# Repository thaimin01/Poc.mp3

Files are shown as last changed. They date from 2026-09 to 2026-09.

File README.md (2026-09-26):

# Poc.mp3
A mp3 player that fit into your pocket. With expandable micro sd storage, cool analog and digital VU meter. An AUX output so everyone is happy. All on the esp32

Schematic

finishedschematic

PCB

raytracedpcb

raytracedpcbback

genuineslop

This has 8 buttons, including:

-5 buttons for navigation: Up, Down, Left, Right, Select

-2 buttons for volume changing: Volume up/down

-1 buttons for locking/unlocking

-Features and ESP32-S3 with 8MB of PSRAM and 16MB of flash (N16R8)

-Analog VU meter and two version of digital VU meter (NCS circle and Flat)

-Able to play pretty much most popular audio file with the ability to load the MP3 embeded images

-With SDMMC 1 bit can loads image and music up to 2MB/s (under ideal conditions)

-A 3.5mm jack output with full on Stereo

-Finally a full on UI with home screen and more !

Bill Of Materials

| Reference | Qty | Value | DNP | Exclude from BOM | Exclude from Board | Exclude from Simulation | Exclude from Position Files | Footprint | Datasheet | Cost (USD) | Note |
|---|-----|---|-----|---|---|---|---|---|---|---|---|
| BT1 | 1 | 3.7V | | | | | ${EXCLUDE_FROM_POS_FILES} | Connector_Wire:SolderWire-0.25sqmm_1x02_P4.2mm_D0.65mm_OD1.7mm | | $2 | single |
| C1,C16,C18,C20,C24,C28 | 6 | 0.1uF | | | | | ${EXCLUDE_FROM_POS_FILES} | Capacitor_SMD:C_0603_1608Metric_Pad1.08x0.95mm_HandSolder | | $0.38 | (10pcs per strip) |
| C2,C3,C4,C15,C17,C19,C23,C29 | 8 | 10uF | | | | | ${EXCLUDE_FROM_POS_FILES} | Capacitor_SMD:C_0805_2012Metric_Pad1.18x1.45mm_HandSolder | | $0.50 | (10pcs per strip) |
| C5,C11 | 2 | 22pF | | | | | ${EXCLUDE_FROM_POS_FILES} | Capacitor_SMD:C_0603_1608Metric_Pad1.08x0.95mm_HandSolder | | $0.38 | (10pcs per strip) |
| C6,C7,C8,C9,C10,C12 | 6 | 22uF | | | | | ${EXCLUDE_FROM_POS_FILES} | Capacitor_SMD:C_0805_2012Metric_Pad1.18x1.45mm_HandSolder | | $1.25 | (50pcs per strip) |
| C13,C14,C30 | 3 | 1uF | | | | | ${EXCLUDE_FROM_POS_FILES} | Capacitor_SMD:C_0603_1608Metric_Pad1.08x0.95mm_HandSolder | | $0.38 | (10pcs per strip) |
| C21,C22 | 2 | 2.2uF | | | | | ${EXCLUDE_FROM_POS_FILES} | Capacitor_SMD:C_0603_1608Metric_Pad1.08x0.95mm_HandSolder | | $0.60 | (10pcs per strip) |
| C25,C26 | 2 | 2.2nF | | | | | ${EXCLUDE_FROM_POS_FILES} | Capacitor_SMD:C_0603_1608Metric_Pad1.08x0.95mm_HandSolder | | $0.50 | (10pcs per strip) |
| C27 | 1 | 0.39uF | | | | | ${EXCLUDE_FROM_POS_FILES} | Capacitor_SMD:C_0603_1608Metric_Pad1.08x0.95mm_HandSolder | | $0.38 | (10pcs per strip) |
| C31,C32 | 2 | 100nF | | | | | ${EXCLUDE_FROM_POS_FILES} | Capacitor_SMD:C_0603_1608Metric_Pad1.08x0.95mm_HandSolder | | $0.38 | (10pcs per strip) |
| D1,D2 | 2 | 1N4148W | | | | | ${EXCLUDE_FROM_POS_FILES} | Diode_SMD:D_SOD-123 | https://www.vishay.com/docs/85748/1n4148w.pdf | $1.35 | (200pcs per strip) |
| D3 | 1 | SS34 | | | | | ${EXCLUDE_FROM_POS_FILES} | Diode_SMD:D_SMA | https://www.vishay.com/docs/88751/ss32.pdf | $0.80 | (10pcs per strip) |
| J1 | 1 | USB_C_Receptacle_USB2.0_16P | | | | | ${EXCLUDE_FROM_POS_FILES} | Connector_USB:USB_C_Receptacle_HRO_TYPE-C-31-M-12 | https://www.usb.org/sites/default/files/documents/usb_type-c.zip | $0.60 | single |
| J2 | 1 | 1.8 in TFT screen ST7735 | | | | | ${EXCLUDE_FROM_POS_FILES} | Connector_PinSocket_2.54mm:PinSocket_1x08_P2.54mm_Vertical | | $2.70 | single |
| J4 | 1 | AudioJack3_SwitchTR | | | | | ${EXCLUDE_FROM_POS_FILES} | Connector_Audio:Jack_3.5mm_CUI_SJ2-3593D-SMT_Horizontal | | $1.50 | single |
| J5 | 1 | Micro_SD_Card_Det_Hirose_DM3AT | | | | | ${EXCLUDE_FROM_POS_FILES} | Connector_Card:microSD_HC_Hirose_DM3AT-SF-PEJM5 | https://www.hirose.com/product/en/download_file/key_name/DM3/category/Catalog/doc_file_id/49662/?item_id=195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 | $4 | single |
| L1 | 1 | 4.7 uH | | | | | ${EXCLUDE_FROM_POS_FILES} | Inductor_SMD:L_Taiyo-Yuden_NR-40xx_HandSoldering | | $2 | (5pcs per strip) |
| L2 | 1 | 2.2 uH | | | | | ${EXCLUDE_FROM_POS_FILES} | Inductor_SMD:L_Taiyo-Yuden_NR-40xx_HandSoldering | | $2 | (5pcs per strip) |
| L3 | 1 | 3.3uH | | | | | ${EXCLUDE_FROM_POS_FILES} | Inductor_SMD:L_Taiyo-Yuden_NR-40xx_HandSoldering | | $2 | (5pcs per strip) |
| LS1 | 1 | Speaker | | | | | ${EXCLUDE_FROM_POS_FILES} | Connector_Wire:SolderWire-0.25sqmm_1x02_P4.2mm_D0.65mm_OD1.7mm | | $1 | single |
| Q1 | 1 | 2N7002 | | | | | ${EXCLUDE_FROM_POS_FILES} | Package_TO_SOT_SMD:SOT-23 | https://www.onsemi.com/pub/Collateral/NDS7002A-D.PDF | $1 | 1 $ (50pcs per strip) |
| R1 | 1 | 1K | | | | | ${EXCLUDE_FROM_POS_FILES} | Resistor_SMD:R_0603_1608Metric_Pad0.98x0.95mm_HandSolder | | $1 | (100pcs per strip) |
| R2 | 1 | 0.05 | | | | | ${EXCLUDE_FROM_POS_FILES} | Resistor_SMD:R_0603_1608Metric_Pad0.98x0.95mm_HandSolder | | $1 | (100pcs per strip) |
| R3 | 1 | 453K | | | | | ${EXCLUDE_FROM_POS_FILES} | Resistor_SMD:R_0603_1608Metric_Pad0.98x0.95mm_HandSolder | | $1 | (100pcs per strip) |
| R4 | 1 | 100K | | | | | ${EXCLUDE_FROM_POS_FILES} | Resistor_SMD:R_0603_1608Metric_Pad0.98x0.95mm_HandSolder | | $1 | (100pcs per strip) |
| R5 | 1 | 43K | | | | | ${EXCLUDE_FROM_POS_FILES} | Resistor_SMD:R_0603_1608Metric_Pad0.98x0.95mm_HandSolder | | $1 | (100pcs per strip) |
| R6 | 1 | 440K | | | | | ${EXCLUDE_FROM_POS_FILES} | Resistor_SMD:R_0603_1608Metric_Pad0.98x0.95mm_HandSolder | | $1 | (100pcs per strip) |
| R7 | 1 | 60K | | | | | ${EXCLUDE_FROM_POS_FILES} | Resistor_SMD:R_0603_1608Metric_Pad0.98x0.95mm_HandSolder | | $1 | (100pcs per strip) |
| R8,R9 | 2 | 470 | | | | | ${EXCLUDE_FROM_POS_FILES} | Resistor_SMD:R_0603_1608Metric_Pad0.98x0.95mm_HandSolder | | $1 | (100pcs per strip) |
| R10 | 1 | 20k | | | | | ${EXCLUDE_FROM_POS_FILES} | Resistor_SMD:R_0603_1608Metric_Pad0.98x0.95mm_HandSolder | | $1 | (100pcs per strip) |
| R11,R12 | 2 | 1k | | | | | ${EXCLUDE_FROM_POS_FILES} | Resistor_SMD:R_0603_1608Metric_Pad0.98x0.95mm_HandSolder | | $1 | (100pcs per strip) |
| R13,R15,R16,R23,R24,R25,R26,R29 | 8 | 10k | | | | | ${EXCLUDE_FROM_POS_FILES} | Resistor_SMD:R_0603_1608Metric_Pad0.98x0.95mm_HandSolder | | $1 | (100pcs per strip) |
| R14,R17,R18,R27,R28,R30 | 6 | 100k | | | | | ${EXCLUDE_FROM_POS_FILES} | Resistor_SMD:R_0603_1608Metric_Pad0.98x0.95mm_HandSolder | | $1 | (100pcs per strip) |
| R19,R20 | 2 | 5.1k | | | | | ${EXCLUDE_FROM_POS_FILES} | Resistor_SMD:R_0603_1608Metric_Pad0.98x0.95mm_HandSolder | | $1 | (100pcs per strip) |
| R31 | 1 | 33 | | | | | ${EXCLUDE_FROM_POS_FILES} | Resistor_SMD:R_0603_1608Metric_Pad0.98x0.95mm_HandSolder | | $1 | (100pcs per strip) |
| SW1 | 1 | Up | | | | | ${EXCLUDE_FROM_POS_FILES} | Button_Switch_SMD:SW_SPST_PTS645Sx43SMTR92 | | | |
| SW2 | 1 | Down | | | | | ${EXCLUDE_FROM_POS_FILES} | Button_Switch_SMD:SW_SPST_PTS645Sx43SMTR92 | | | |
| SW3 | 1 | Left | | | | | ${EXCLUDE_FROM_POS_FILES} | Button_Switch_SMD:SW_SPST_PTS645Sx43SMTR92 | | | |
| SW4 | 1 | Right | | | | | ${EXCLUDE_FROM_POS_FILES} | Button_Switch_SMD:SW_SPST_PTS645Sx43SMTR92 | | | |
| SW5 | 1 | Select | | | | | ${EXCLUDE_FROM_POS_FILES} | Button_Switch_SMD:SW_SPST_PTS645Sx43SMTR92 | | $0.60 | (20pcs per package) |
| SW6 | 1 | Volume + | | | | | ${EXCLUDE_FROM_POS_FILES} | Button_Switch_SMD:SW_SPST_PTS645Sx43SMTR92 | | | |
| SW7 | 1 | Volume - | | | | | ${EXCLUDE_FROM_POS_FILES} | Button_Switch_SMD:SW_SPST_PTS645Sx43SMTR92 | | | |
| SW8 | 1 | Lock/unlock | | | | | ${EXCLUDE_FROM_POS_FILES} | Button_Switch_SMD:SW_SPST_PTS645Sx43SMTR92 | | | |
| SW9 | 1 | Reset | | | | | ${EXCLUDE_FROM_POS_FILES} | Button_Switch_SMD:SW_SPST_EVQP2_MiddlePushTravel_H2.5mm | | | |
| U1 | 1 | XBB608A | | | | | ${EXCLUDE_FROM_POS_FILES} | Package_SO:SOIC-8-1EP_3.9x4.9mm_P1.27mm_EP2.29x3mm | | | |
| U2 | 1 | TP5000X-4.2-ESOP8 | | | | | ${EXCLUDE_FROM_POS_FILES} | Package_SO:SOIC-8-1EP_3.9x4.9mm_P1.27mm_EP2.29x3mm | TP5000X-4.2-ESOP8 | $1.15 | (10pcs per package) |
| U3 | 1 | SY8089AAAC | | | | | ${EXCLUDE_FROM_POS_FILES} | footprints:SY8089AAAC_SGY | SY8089AAAC | $1.60 | (10pcs per strip) |
| U4 | 1 | LM4871M | | | | | ${EXCLUDE_FROM_POS_FILES} | LM4871M:SOIC127P599X175-8N | | $2 | single |
| U5 | 1 | ESP32-S3-WROOM-1 | | | | | ${EXCLUDE_FROM_POS_FILES} | RF_Module:ESP32-S3-WROOM-1 | https://www.espressif.com/sites/default/files/documentation/esp32-s3-wroom-1_wroom-1u_datasheet_en.pdf | $5 | single |
| U6 | 1 | PCM5102A | | | | | ${EXCLUDE_FROM_POS_FILES} | Package_SO:TSSOP-20_4.4x6.5mm_P0.65mm | https://www.ti.com/lit/ds/symlink/pcm5102a.pdf | $2.70 | single |
| U7 | 1 | FP6276B | | | | | ${EXCLUDE_FROM_POS_FILES} | Package_SO:SOIC-8-1EP_3.9x4.9mm_P1.27mm_EP2.29x3mm | | $4.50 | (5pcs package) |
| | | | | | | | | | Total | 57.25 | $ |

Cost

5pcs of 4 layers PCB: ~$30.00 (for 55.245mm x 102.133)

Total of the components: ~$57.25

If you want to do 3d printing: ~$22.00 in ABS material

Total: 87.25 $ or 102.25 $

Get $100 - $125, this might give you some headroom depends on your country !!!!

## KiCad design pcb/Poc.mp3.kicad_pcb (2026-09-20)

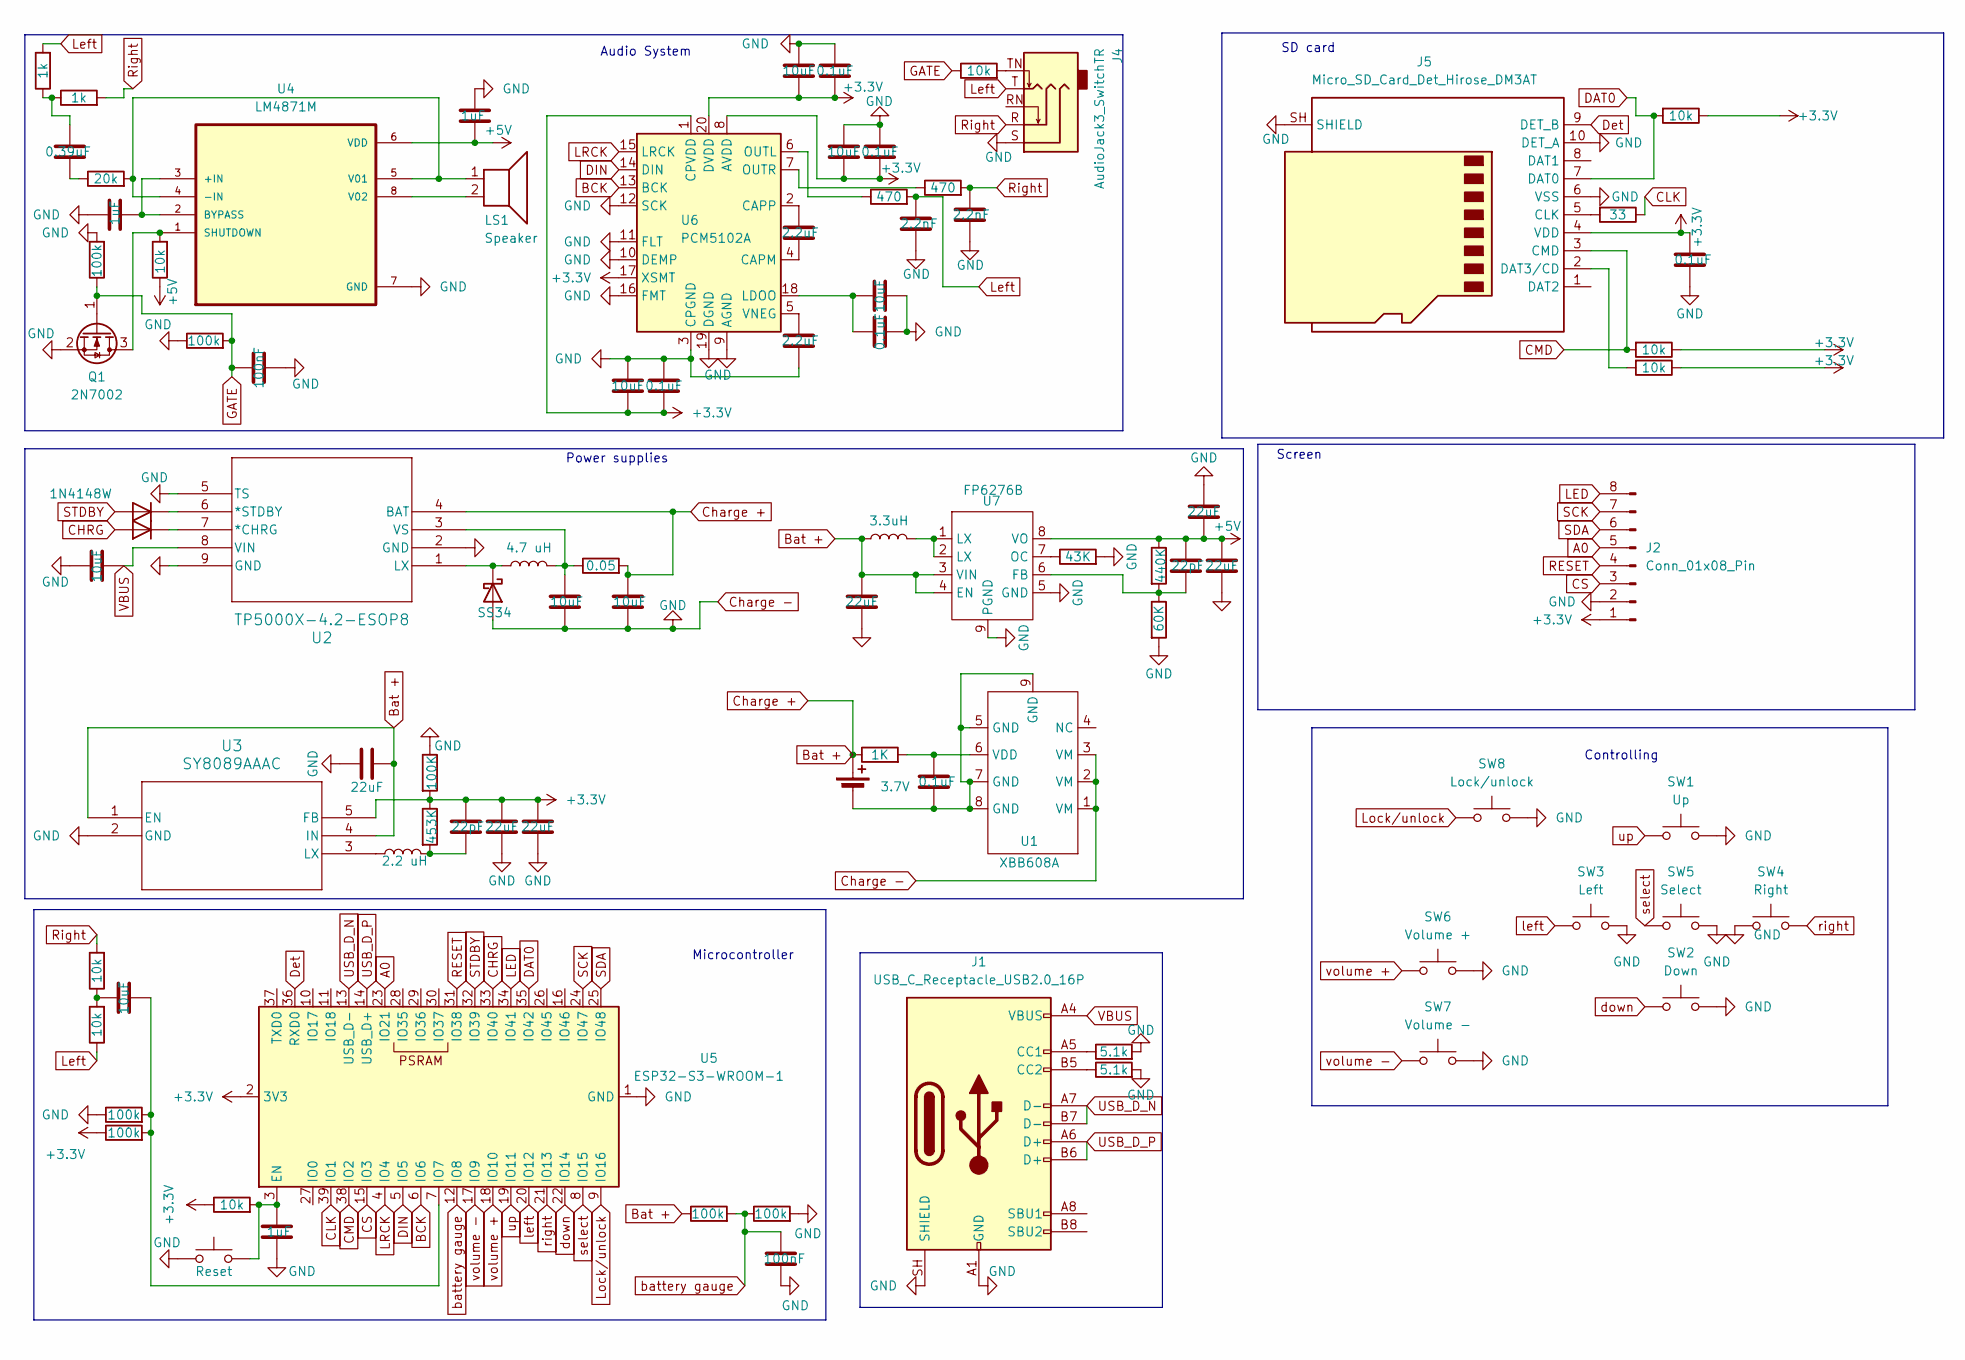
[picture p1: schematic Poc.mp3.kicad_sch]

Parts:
BT1: 3.7V; SolderWire-0.25sqmm_1x02_P4.2mm_D0.65mm_OD1.7mm
C1, C16, C18, C20, C24, C28: 0.1uF; C_0603_1608Metric_Pad1.08x0.95mm_HandSolder
C2, C3, C4, C15, C17, C19, C23, C29: 10uF; C_0805_2012Metric_Pad1.18x1.45mm_HandSolder
C5, C11: 22pF; C_0603_1608Metric_Pad1.08x0.95mm_HandSolder
C6, C7, C8, C9, C10, C12: 22uF; C_0805_2012Metric_Pad1.18x1.45mm_HandSolder
C13, C14, C30: 1uF; C_0603_1608Metric_Pad1.08x0.95mm_HandSolder
C21, C22: 2.2uF; C_0603_1608Metric_Pad1.08x0.95mm_HandSolder
C25, C26: 2.2nF; C_0603_1608Metric_Pad1.08x0.95mm_HandSolder
C27: 0.39uF; C_0603_1608Metric_Pad1.08x0.95mm_HandSolder
C31, C32: 100nF; C_0603_1608Metric_Pad1.08x0.95mm_HandSolder
D1, D2: 1N4148W; D_SOD-123
D3: SS34; D_SMA
J1: USB_C_Receptacle_USB2.0_16P; USB_C_Receptacle_HRO_TYPE-C-31-M-12
J2: Conn_01x08_Pin; PinSocket_1x08_P2.54mm_Vertical
J4: AudioJack3_SwitchTR; Jack_3.5mm_CUI_SJ2-3593D-SMT_Horizontal
J5: Micro_SD_Card_Det_Hirose_DM3AT; microSD_HC_Hirose_DM3AT-SF-PEJM5
L1: 4.7 uH; L_Taiyo-Yuden_NR-40xx_HandSoldering
L2: 2.2 uH; L_Taiyo-Yuden_NR-40xx_HandSoldering
L3: 3.3uH; L_Taiyo-Yuden_NR-40xx_HandSoldering
LS1: Speaker; SolderWire-0.25sqmm_1x02_P4.2mm_D0.65mm_OD1.7mm
Q1: 2N7002; SOT-23
R1: 1K; R_0603_1608Metric_Pad0.98x0.95mm_HandSolder
R2: 0.05; R_0603_1608Metric_Pad0.98x0.95mm_HandSolder
R3: 453K; R_0603_1608Metric_Pad0.98x0.95mm_HandSolder
R4: 100K; R_0603_1608Metric_Pad0.98x0.95mm_HandSolder
R5: 43K; R_0603_1608Metric_Pad0.98x0.95mm_HandSolder
R6: 440K; R_0603_1608Metric_Pad0.98x0.95mm_HandSolder
R7: 60K; R_0603_1608Metric_Pad0.98x0.95mm_HandSolder
R8, R9: 470; R_0603_1608Metric_Pad0.98x0.95mm_HandSolder
R10: 20k; R_0603_1608Metric_Pad0.98x0.95mm_HandSolder
R11, R12: 1k; R_0603_1608Metric_Pad0.98x0.95mm_HandSolder
R13, R15, R16, R23, R24, R25, R26, R29: 10k; R_0603_1608Metric_Pad0.98x0.95mm_HandSolder
R14, R17, R18, R27, R28, R30: 100k; R_0603_1608Metric_Pad0.98x0.95mm_HandSolder
R19, R20: 5.1k; R_0603_1608Metric_Pad0.98x0.95mm_HandSolder
R31: 33; R_0603_1608Metric_Pad0.98x0.95mm_HandSolder
SW1: Up; SW_SPST_PTS645Sx43SMTR92
SW2: Down; SW_SPST_PTS645Sx43SMTR92
SW3: Left; SW_SPST_PTS645Sx43SMTR92
SW4: Right; SW_SPST_PTS645Sx43SMTR92
SW5: Select; SW_SPST_PTS645Sx43SMTR92
SW6: Volume +; SW_SPST_PTS645Sx43SMTR92
SW7: Volume -; SW_SPST_PTS645Sx43SMTR92
SW8: Lock/unlock; SW_SPST_PTS645Sx43SMTR92
SW9: Reset; SW_SPST_EVQP2_MiddlePushTravel_H2.5mm
U1: XBB608A; SOIC-8-1EP_3.9x4.9mm_P1.27mm_EP2.29x3mm
U2: TP5000X-4.2-ESOP8; SOIC-8-1EP_3.9x4.9mm_P1.27mm_EP2.29x3mm
U3: SY8089AAAC; SY8089AAAC_SGY
U4: LM4871M; SOIC127P599X175-8N
U5: ESP32-S3-WROOM-1
U6: PCM5102A; TSSOP-20_4.4x6.5mm_P0.65mm
U7: FP6276B; SOIC-8-1EP_3.9x4.9mm_P1.27mm_EP2.29x3mm

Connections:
+3.3V: C5.2, C6.1, C8.1, C17.2, C18.2, C19.2, C20.2, C23.2, C24.2, C28.1, J2.1, J5.4 (VDD), R3.1, R4.2, R18.1, R23.1, R24.1, R25.1, R26.1, U3.5 (FB), U5.2 (3V3), U6.1 (CPVDD), U6.8 (AVDD), U6.17 (XSMT), U6.20 (DVDD)
+5V: C9.1, C10.1, C11.2, C14.1, R6.1, R13.1, U4.6 (VDD), U7.8 (VO)
A0: J2.5, U5.23 (IO21)
BCK: U5.6 (IO6), U6.13 (BCK)
Bat +: BT1.1 (+), C3.2, C7.2, C12.1, L3.1, R1.1, R2.2, R27.1, U2.4 (BAT), U3.1 (EN), U3.4 (IN), U7.3 (VIN), U7.4 (EN)
CHRG: D1.2 (A), U5.33 (IO40)
CLK: R31.1, U5.39 (IO1)
CMD: J5.3 (CMD), R23.2, U5.38 (IO2)
CS: J2.3, U5.15 (IO3)
Charge -: C2.1, C3.1, C4.1, C6.2, C7.1, C8.2, C9.2, C10.2, C12.2, C13.1, C14.2, C15.1, C16.1, C17.1, C18.1, C19.1, C20.1, C21.2, C23.1, C24.1, C25.2, C26.2, C28.2, C30.2, C31.2, C32.2, D3.2 (A), J1.A1 (GND), J1.A12 (GND), J1.B1 (GND), J1.B12 (GND), J1.SH (SHIELD), J2.2, J4.S, J5.6 (VSS), J5.10 (DET_A), J5.SH (SHIELD), Q1.2 (S), R4.1, R5.2, R7.2, R14.2, R17.1, R19.2, R20.2, R28.2, R30.1, SW1.2, SW2.2, SW3.2, SW4.1, SW5.2, SW6.2, SW7.2, SW8.2, SW9.1, U1.1 (VM), U1.2 (VM), U1.3 (VM), U2.2 (GND), U2.5 (TS), U2.9 (GND), U3.2 (GND), U4.7 (GND), U5.1 (GND), U5.40 (GND), U5.41 (GND), U6.3 (CPGND), U6.9 (AGND), U6.10 (DEMP), U6.11 (FLT), U6.12 (SCK), U6.16 (FMT), U6.19 (DGND), U7.5 (GND), U7.9 (PGND)
DAT0: J5.7 (DAT0), R24.2, U5.35 (IO42)
DIN: U5.5 (IO5), U6.14 (DIN)
Det: J5.9 (DET_B), U5.36 (RXD0)
GATE: C32.1, Q1.1 (G), R14.1, R29.1, R30.2
LED: J2.8, U5.34 (IO41)
LRCK: U5.4 (IO4), U6.15 (LRCK)
Left: C26.1, J4.T, R9.2, R11.2, R15.1
Lock/unlock: SW8.1, U5.9 (IO16)
unnamed: BT1.2 (-), C1.2, U1.5 (GND), U1.7 (GND), U1.8 (GND), U1.9 (GND)
unnamed: C5.1, L2.2, R3.2
unnamed: C27.1, R10.1
unnamed: C27.2, R11.1, R12.1
unnamed: C29.1, R15.2, R16.1
unnamed: D1.1 (K), U2.7 (*CHRG)
unnamed: D2.1 (K), U2.6 (*STDBY)
unnamed: D3.1 (K), L1.1, U2.1 (LX)
unnamed: J1.A5 (CC1), R19.1
unnamed: J1.B5 (CC2), R20.1
unnamed: J4.TN, R29.2
unnamed: J5.5 (CLK), R31.2
unnamed: J5.2 (DAT3/CD), R25.2
unnamed: L3.2, U7.1 (LX), U7.2 (LX)
unnamed: Q1.3 (D), R13.2, U4.1 (SHUTDOWN)
unnamed: C1.1, R1.2, U1.6 (VDD)
unnamed: C4.2, L1.2, R2.1, U2.3 (VS)
unnamed: L2.1, U3.3 (LX)
unnamed: C13.2, U4.2 (BYPASS), U4.3 (+IN)
unnamed: LS1.1, R10.2, U4.4 (-IN), U4.5 (V01)
unnamed: LS1.2, U4.8 (V02)
unnamed: C30.1, R26.2, SW9.2, U5.3 (EN)
unnamed: C29.2, R17.2, R18.2, U5.7 (IO7)
unnamed: C22.2, U6.4 (CAPM)
unnamed: C22.1, U6.2 (CAPP)
unnamed: C15.2, C16.2, U6.18 (LDOO)
unnamed: R9.1, U6.6 (OUTL)
unnamed: R8.1, U6.7 (OUTR)
unnamed: C21.1, U6.5 (VNEG)
unnamed: C11.1, R6.2, R7.1, U7.6 (FB)
unnamed: R5.1, U7.7 (OC)
RESET: J2.4, U5.31 (IO38)
Right: C25.1, J4.R, R8.2, R12.2, R16.2
SCK: J2.7, U5.24 (IO47)
SDA: J2.6, U5.25 (IO48)
STDBY: D2.2 (A), U5.32 (IO39)
USB_D_N: J1.A7 (D-), J1.B7 (D-), U5.13 (USB_D-)
USB_D_P: J1.A6 (D+), J1.B6 (D+), U5.14 (USB_D+)
VBUS: C2.2, J1.A4 (VBUS), J1.A9 (VBUS), J1.B4 (VBUS), J1.B9 (VBUS), U2.8 (VIN)
battery gauge: C31.1, R27.2, R28.1, U5.12 (IO8)
down: SW2.1, U5.22 (IO14)
left: SW3.1, U5.20 (IO12)
right: SW4.2, U5.21 (IO13)
select: SW5.1, U5.8 (IO15)
up: SW1.1, U5.19 (IO11)
volume +: SW6.1, U5.18 (IO10)
volume -: SW7.1, U5.17 (IO9)

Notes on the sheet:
Microcontroller
Audio System
SD card
Screen
Controlling
Power supplies

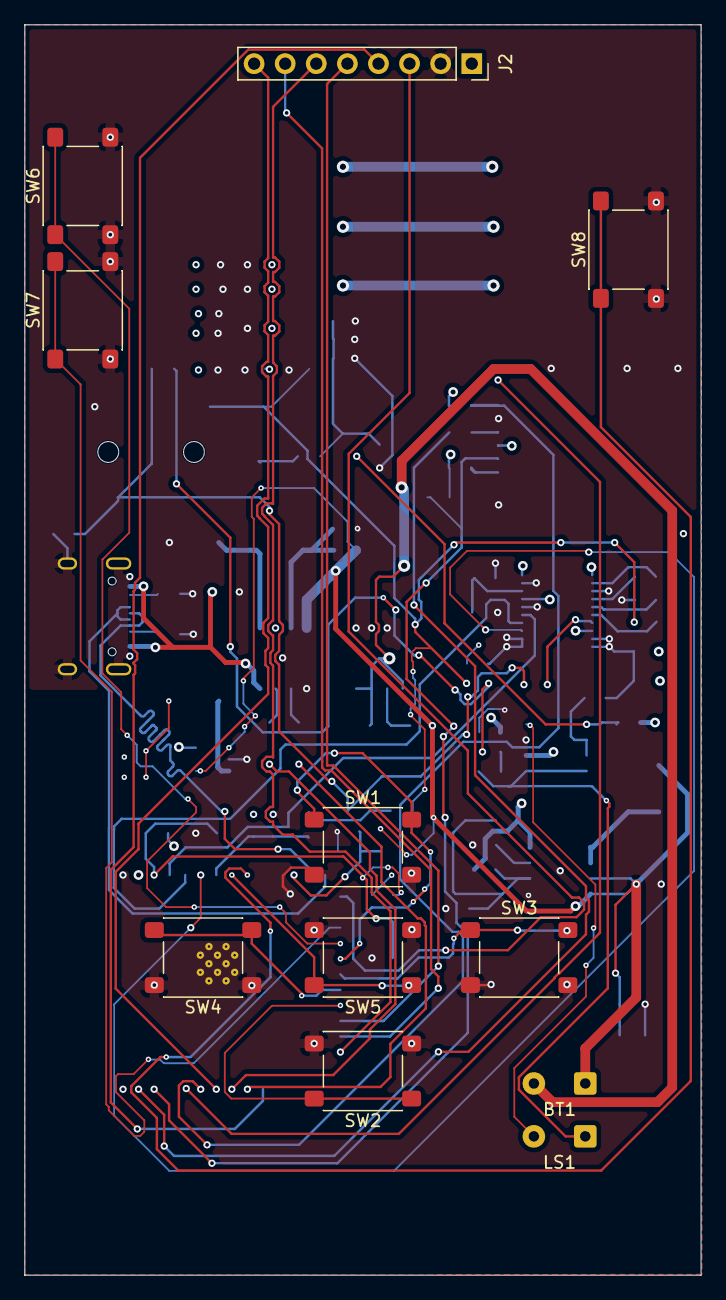
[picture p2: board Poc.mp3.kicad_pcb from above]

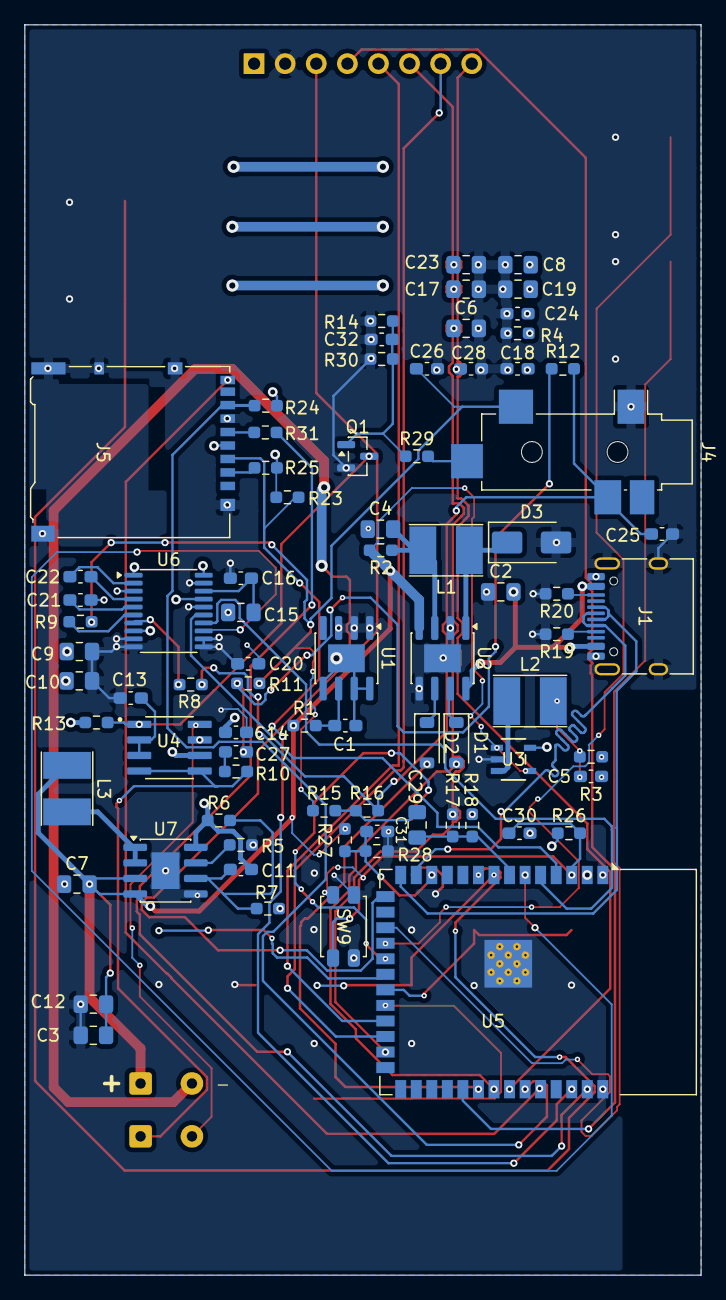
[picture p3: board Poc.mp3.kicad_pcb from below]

Board: 4 copper layers, 55.2 x 102.1 mm, 90 parts (79 on the bottom side), 65 nets.
